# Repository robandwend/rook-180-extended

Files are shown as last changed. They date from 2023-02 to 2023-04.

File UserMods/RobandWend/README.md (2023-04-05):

# ROOK-180 - mods by robandwend (Robertg)

## THIS IS A WORK IN PROGRESS - CHANGES ARE LIKELY

## PLAN

My plan is to build a Rook-180, extended in the Y by 100mm to allow room for 3 hotends (either 3 TD6S's or 4 if I use the Bambu hotends and bowden again) that are give me multi-filament printing.

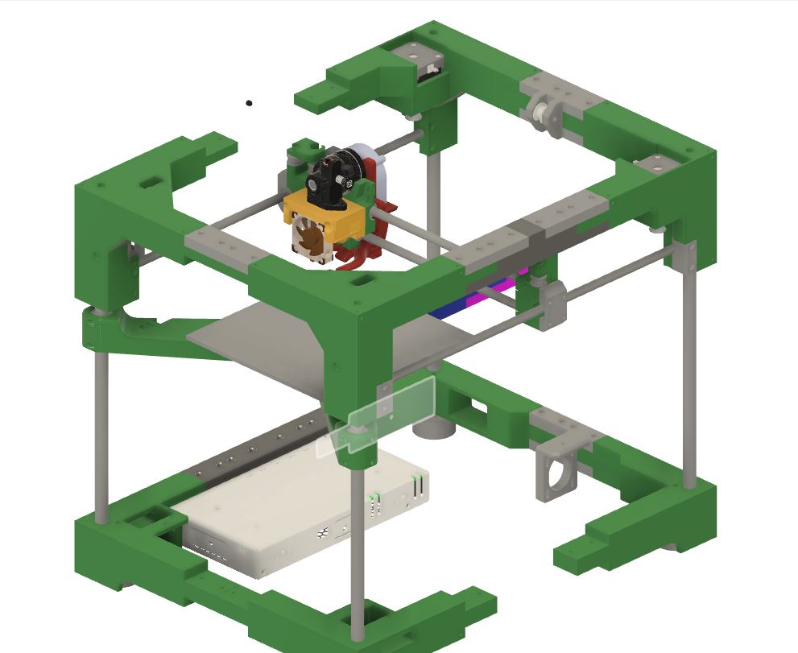
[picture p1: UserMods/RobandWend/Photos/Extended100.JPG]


The bed will still be 180x180, slightly further back (10mm) due to the hotend being rotated 180°. This rotation lets it be driven to the back, where a pair of clips will clip on, and allow the hotend to detatched. The clips on the rear being opened/closed by a strong servo. The hotends will rest on two spikes that fit into the holes on the hotend. (Hopefully this explanation it will make sense as I post more photos). 

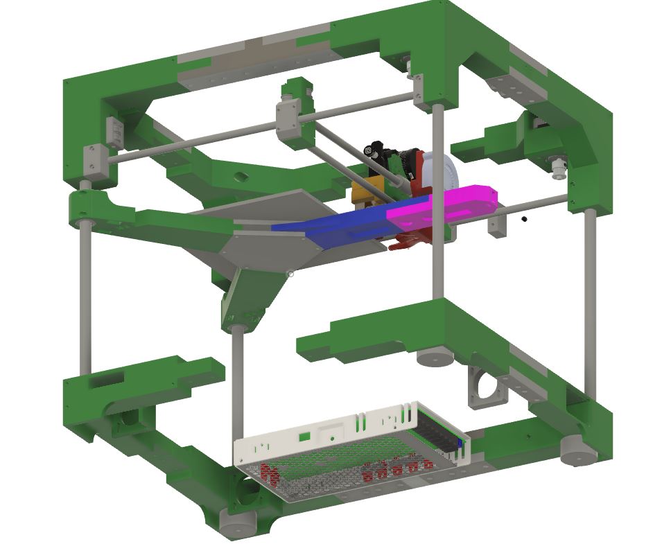
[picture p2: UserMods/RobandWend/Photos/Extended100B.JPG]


Each hotend will need it's own wiring, and will carry the power for the cooling fan. The cooling fan and probe will remain on the X-Carriage, power/cables being passed to it from the removable front.

The hotend design is almost finished - see images. This required squeezing in the magnets, and some position-locking pyramids, I've weight tested the design using simple blocks with the magnets/pyramids and weights etc, and the connection appears very stable and strong. 

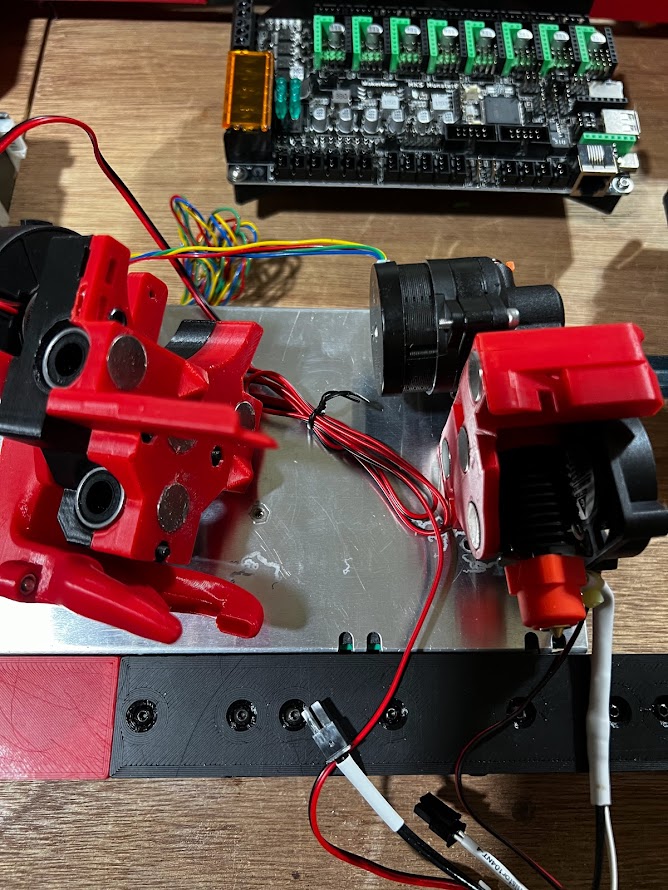
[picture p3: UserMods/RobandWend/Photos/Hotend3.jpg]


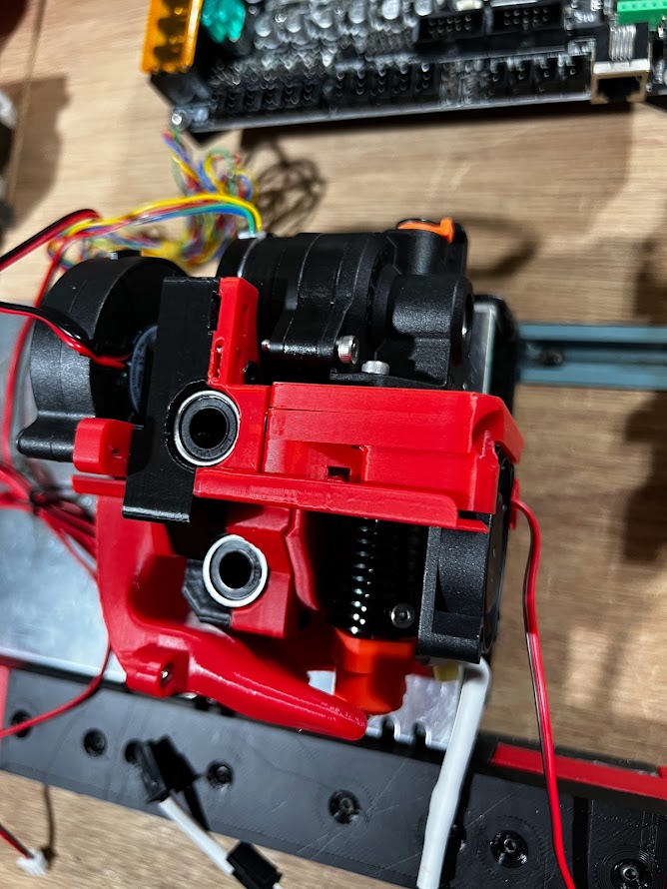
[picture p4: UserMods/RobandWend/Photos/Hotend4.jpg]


The design required me to add 4mm to the front length of the hotend and reducing the rear by 4 - thus keeping the part cooling correctly positioned.

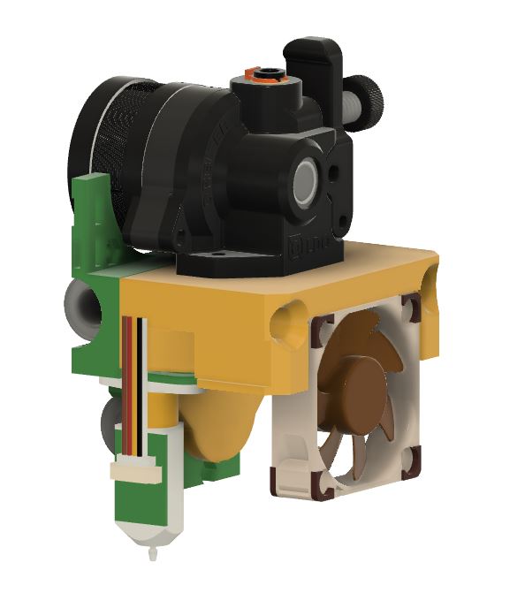
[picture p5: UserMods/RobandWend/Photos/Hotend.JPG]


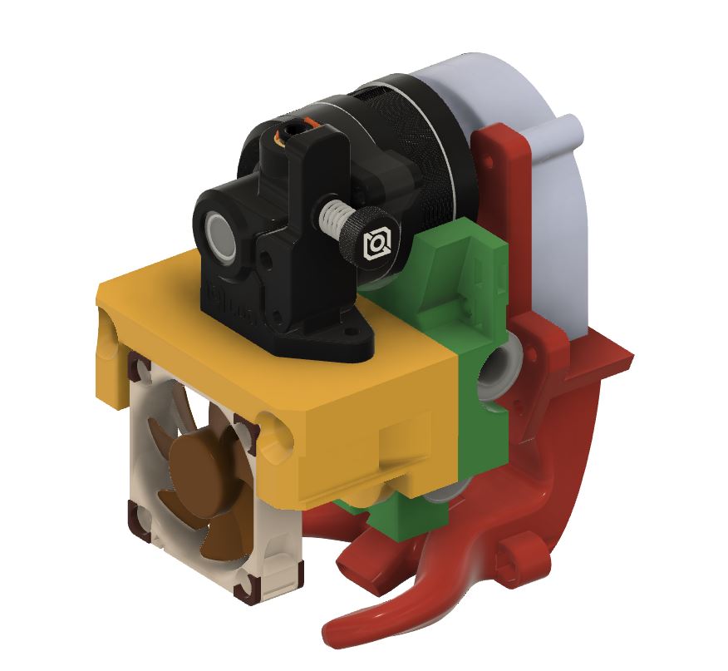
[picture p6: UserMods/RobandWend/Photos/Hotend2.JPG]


I've also had to move the probe back very close to the X rods ** DESIGN NOLONGER HAS THIS CHANGE ** , to allow it to remain with the gantry when the hotends switch. One final thing I need to do is slightly modify the left part cooling pipework to correctly go around the probe.

Here's the current status...

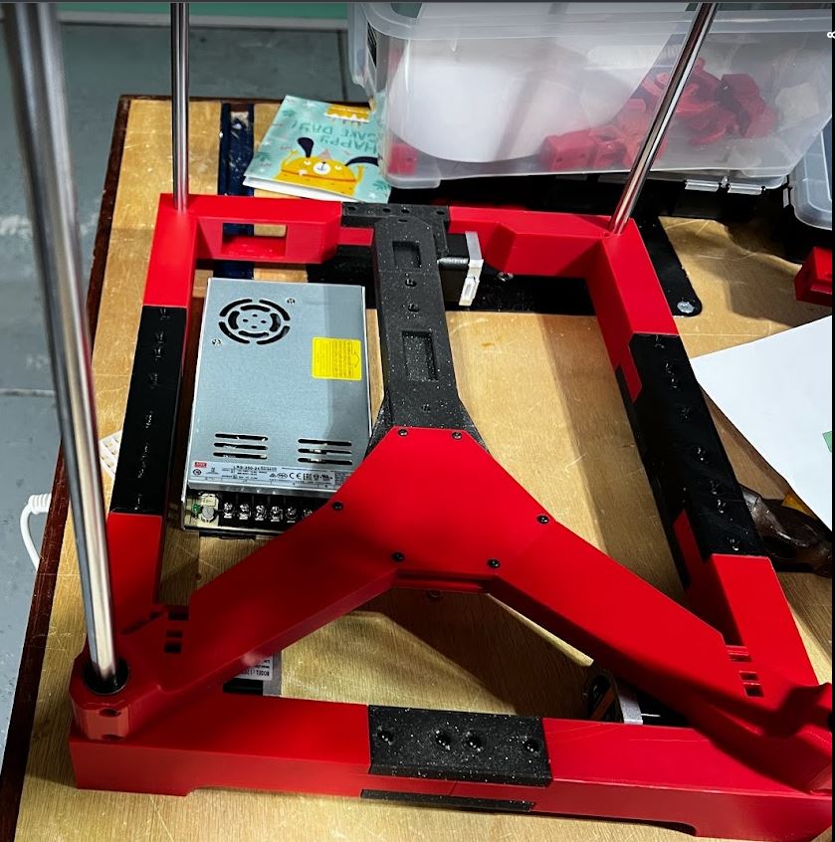
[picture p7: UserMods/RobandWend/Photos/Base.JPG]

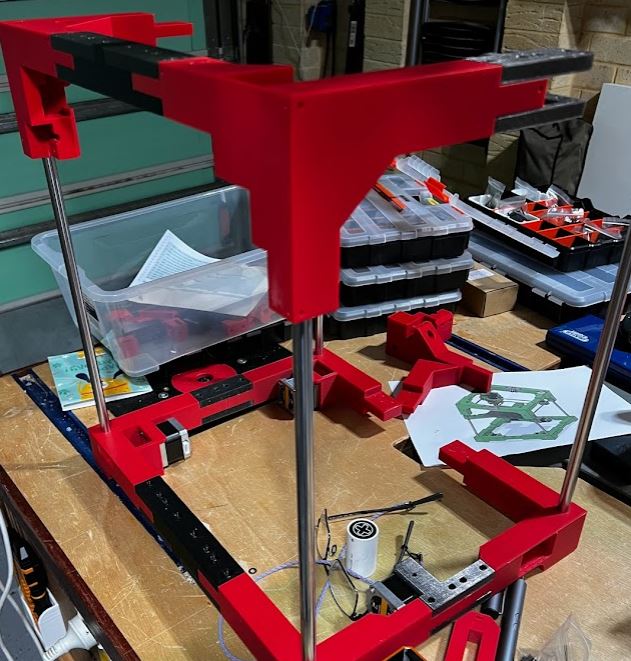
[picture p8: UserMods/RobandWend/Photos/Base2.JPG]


# 12864

Also created a 12864 Display Bracket that fits as a replacement front top brace.

This is not specific to the extended 180

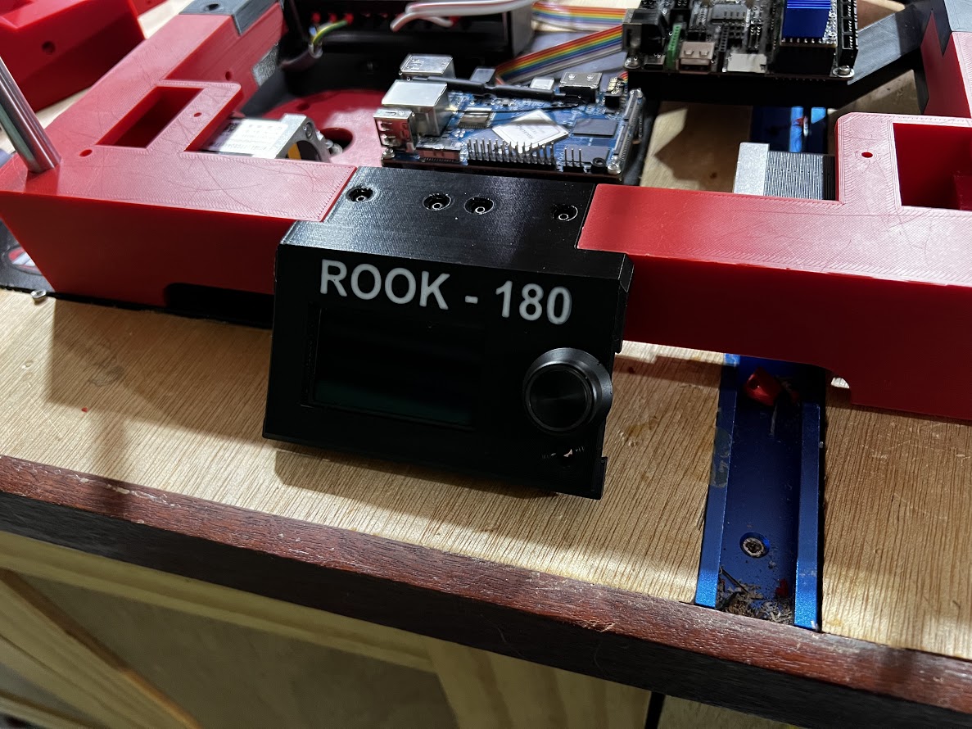
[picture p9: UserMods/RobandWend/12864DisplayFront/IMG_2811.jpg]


# MKS MONSTER8 Mount

This mount is specific to the extended 180, and replaces both the middle lower right braces, extending out to mount the Monster8.

A similar mount it available for an Orange PI 4 LTS based off the front middle brace - as seen in photo below.

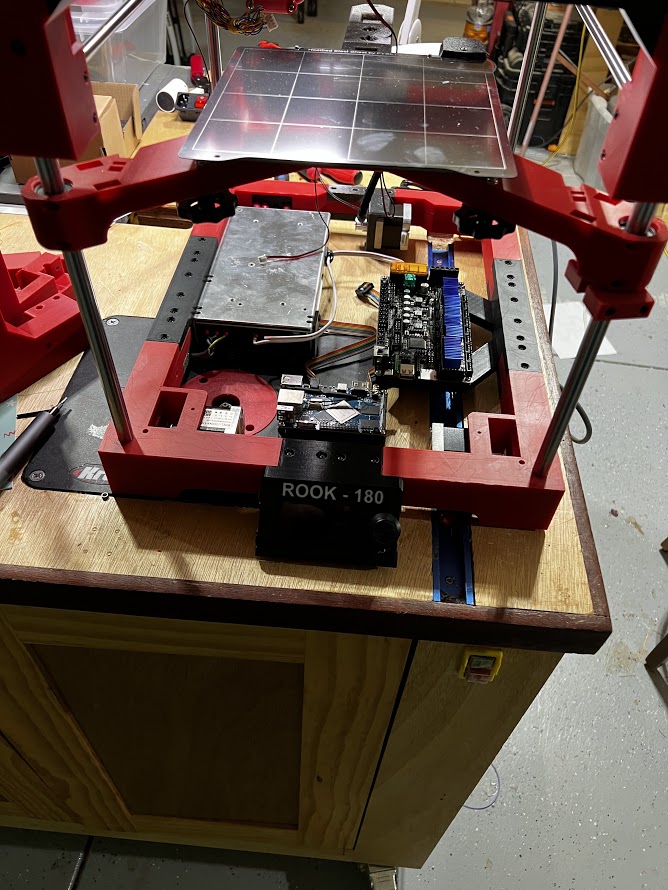
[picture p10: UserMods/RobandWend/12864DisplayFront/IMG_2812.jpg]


# PI MOUNT

There are actually two similar PI mounts available, initially I was using an orangepi 4 LTS, however due to problems getting the gpio working (as a secondary MCU) - I reverted to an raspberry-pi 4b 

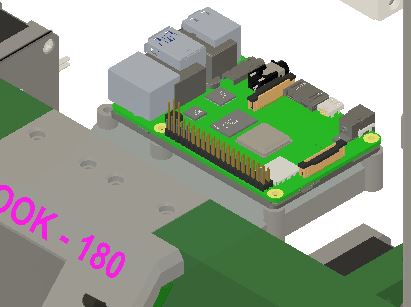
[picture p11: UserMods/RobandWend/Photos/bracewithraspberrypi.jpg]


# MEX - Multi Extruder

## Rear Hotend Storage Area 

To allow for multi-extrude, a rear hotend storage area has been designed.

See videos for design details
* [link](https://www.youtube.com/watch?v=4AOfrqeOWYA) - MEX Development PT1
* [link](https://youtu.be/aWfg_-3LOak) - MEX Development PT2
* [link](https://youtube.com/shorts/aSd3smGOrIA) - MEX Hotend

## Fan cooling and bl-touch

The whole hotend has been reversed (so part cooling fan now at the front). The wiring for the part-cooling fan and the bl-touch remain on the x-carriage at all times. The 5015 adaptor has a small change to allow the wiring to be neatly attached. Current plan is to use a non-functioning piece of bowden to route these two wires to the board. The bl-touch wiring will be routed between the two x-rods.

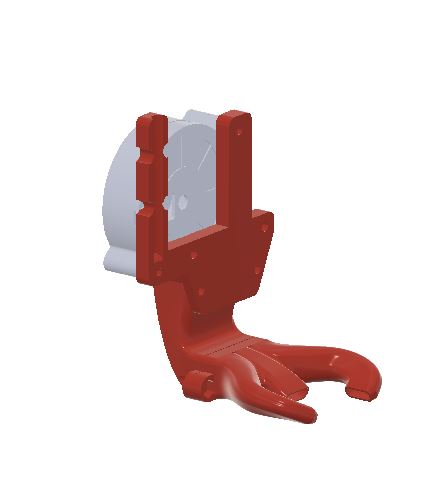
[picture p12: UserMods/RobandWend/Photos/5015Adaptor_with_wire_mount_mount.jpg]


## Bowden Extruders

Clip on bowden extruder mounts (for basic cheapest extruders) have been added

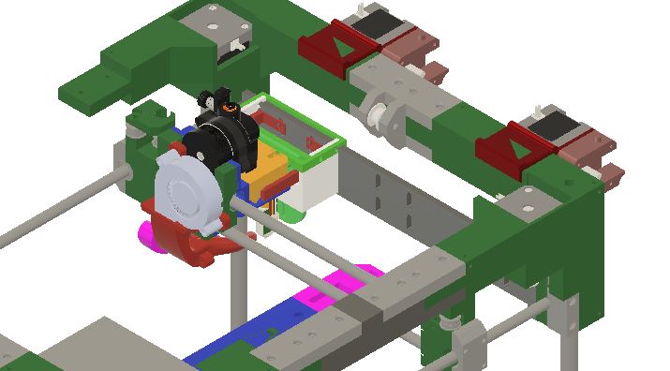
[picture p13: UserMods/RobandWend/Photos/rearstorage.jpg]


Or you could use some Voron M4 Extruders

* [voron design M4 Extruder](https://vorondesign.com/voron_m4)

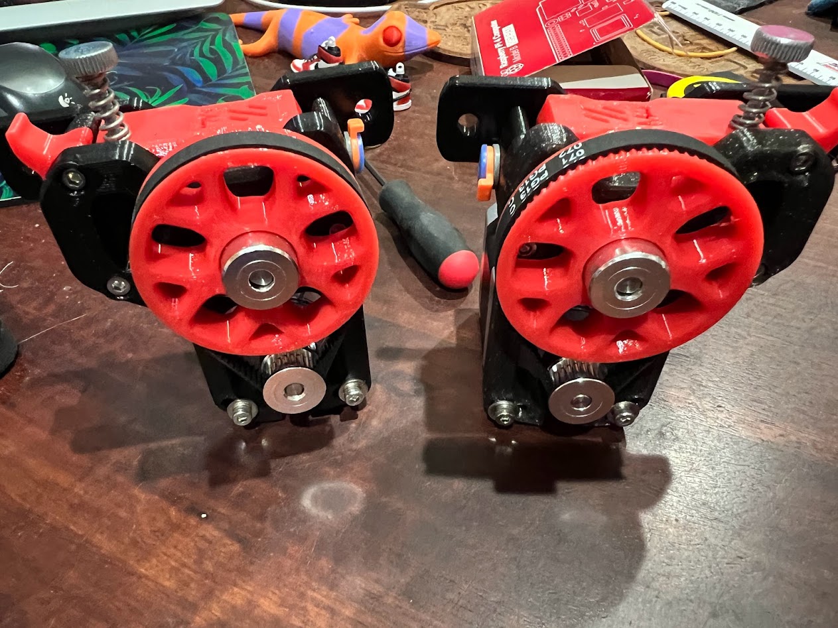
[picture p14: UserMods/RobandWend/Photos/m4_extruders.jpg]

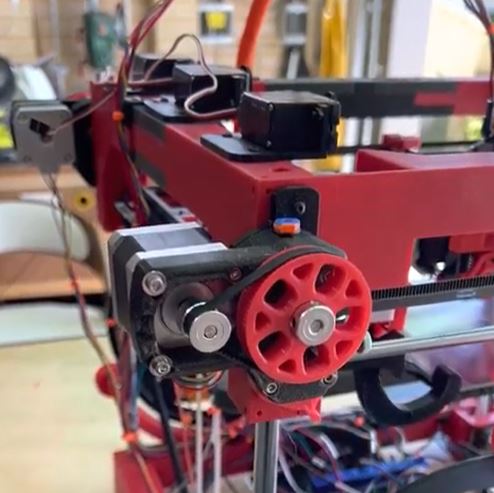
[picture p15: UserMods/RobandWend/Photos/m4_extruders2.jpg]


## Bambu bowden hotend

Since the bambu hotend is quite cheap, and speedwise beats many expensive nozzles, like in my original Rook mods I've added a bambu hotend (for bowden). This has options for either a standard cooling far, or one of the smaller bambu size 2020 fans.

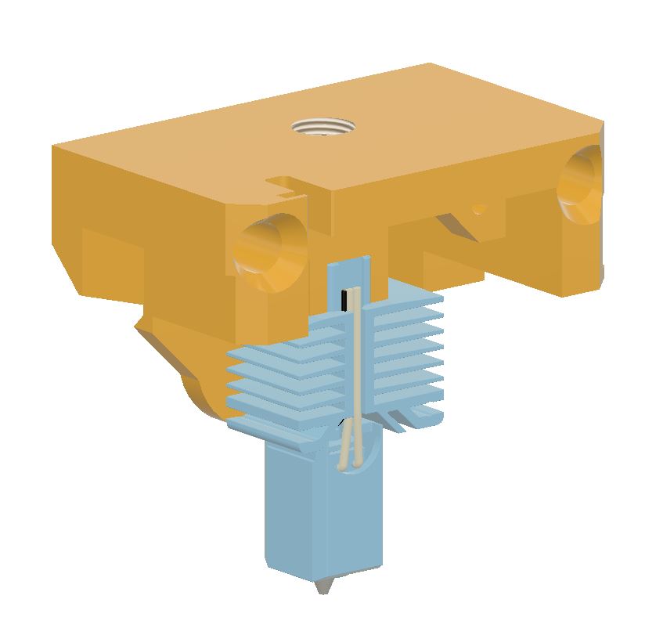
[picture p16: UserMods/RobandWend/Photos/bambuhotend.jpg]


# Endstops
## Z-Endstop

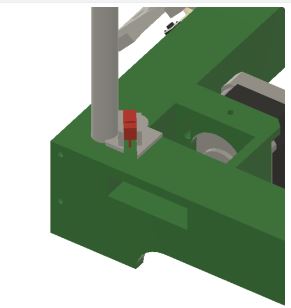
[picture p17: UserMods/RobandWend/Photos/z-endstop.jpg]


# Horseshoe Spool holder

I chose to fit two horseshoe spoolholders to either side

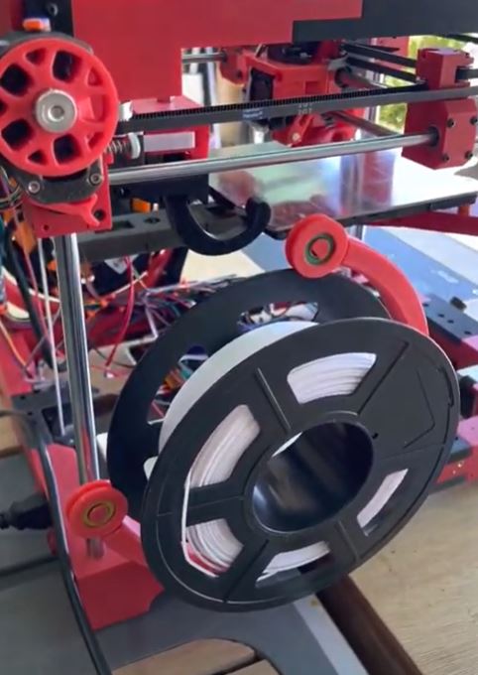
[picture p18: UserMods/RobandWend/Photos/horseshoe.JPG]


From https://github.com/VoronDesign/VoronUsers/tree/master/printer_mods/LoganFraser/HorseshoeSpoolHolder 

Note - for my specific spool size (195mm diameter) a resized STL is provided.

# WIRING - TIDY

I designed a simple wiring scaffold to help keep all the cables tidy.

See [printables link](https://www.printables.com/model/443258-variable-size-scaffold-structure-to-aid-tidying-wi) 

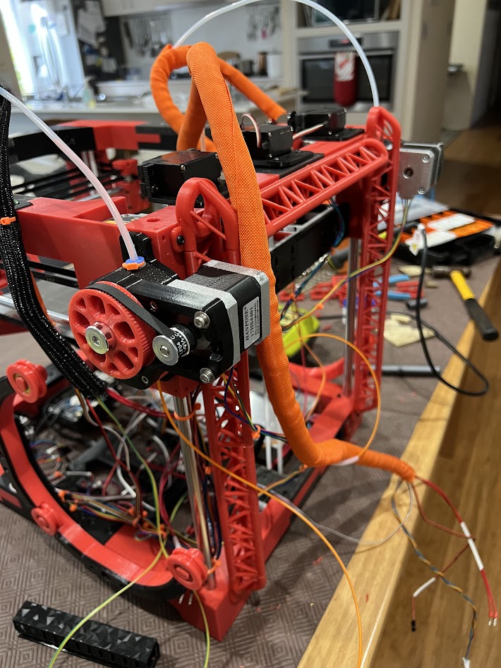
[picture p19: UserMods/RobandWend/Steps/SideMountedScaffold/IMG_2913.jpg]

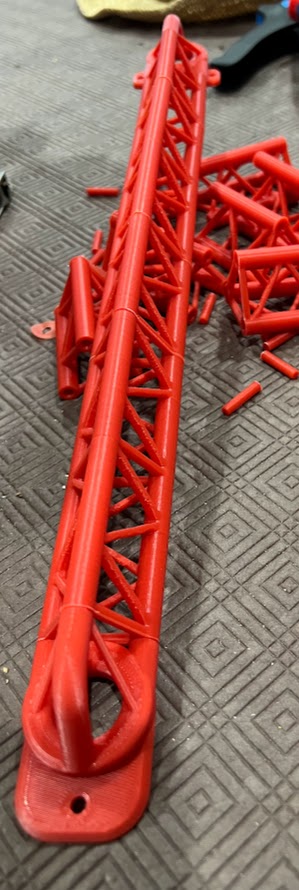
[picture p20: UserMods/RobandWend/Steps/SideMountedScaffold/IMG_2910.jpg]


![Image]()

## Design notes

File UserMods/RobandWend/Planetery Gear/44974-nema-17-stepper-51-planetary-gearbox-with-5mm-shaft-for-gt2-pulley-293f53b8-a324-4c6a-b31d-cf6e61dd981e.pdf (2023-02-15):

## Nema 17 Stepper 5:1 Planetary

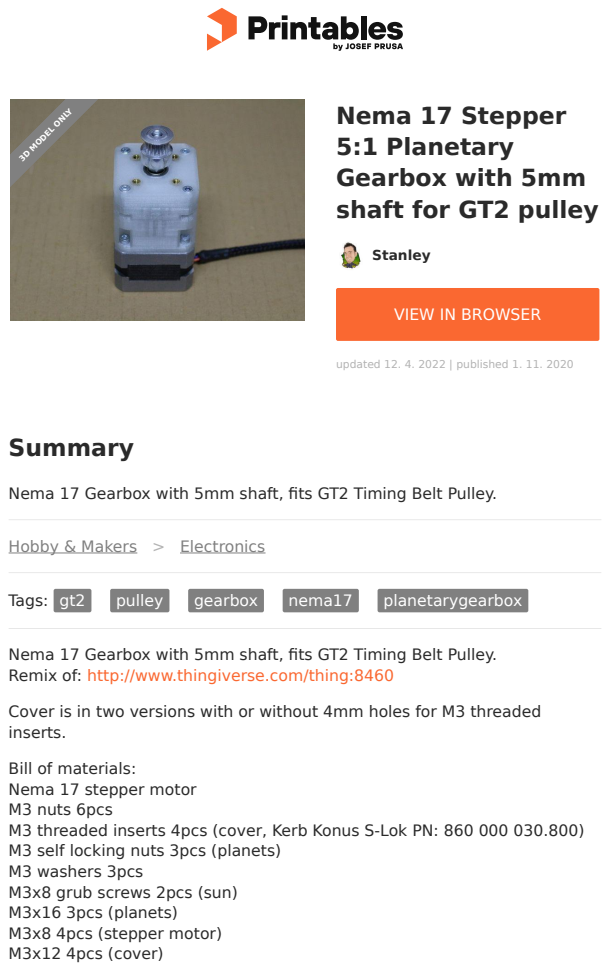
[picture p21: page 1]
Summary; Tags: gt2; pulley; gearbox; nema17; planetarygearbox; Stanley; updated 12. 4. 2022 | published 1. 11. 2020; 3D MODEL ONLY

Gearbox with 5mm
shaft for GT2 pulley

VIEW IN BROWSER (https://www.printables.com/model/44974-nema-17-stepper-51-planetary-gearbox-with-5mm-shaf)

Nema 17 Gearbox with 5mm shaft, fits GT2 Timing Belt Pulley.

Hobby & Makers (https://www.printables.com/model?categoryId=48) > Electronics (https://www.printables.com/model?categoryId=52)

Remix of: http://www.thingiverse.com/thing:8460

Cover is in two versions with or without 4mm holes for M3 threaded
inserts.

Bill of materials:
Nema 17 stepper motor
M3 nuts 6pcs
M3 threaded inserts 4pcs (cover, Kerb Konus S-Lok PN: 860 000 030.800)
M3 self locking nuts 3pcs (planets)
M3 washers 3pcs
M3x8 grub screws 2pcs (sun)
M3x16 3pcs (planets)
M3x8 4pcs (stepper motor)
M3x12 4pcs (cover)

## Model files

M5x30 1pcs (shaft)
M5 self locking nuts 1pcs (shaft)
695zz ball bearing 2pcs (shaft)
683zz ball bearing 6pcs (planets, 2pcs each)

Print instructions

Rafts: No

Supports: Yes

Resolution: 0.1mm - 0.2mm

Infill: 40% - 100%

Notes:

Filament: PET 1.75mm (http://www.filament-pm.cz/) Sliced in: Cura 15.04.2
Nozzle: 0.4mm
Shell thickness: 1.2mm
Bottom/Top thickness: 1.2mm Print speed: 30mm/s
Print temp: 235°C
Bed temp: 80°C
Planets and sun printed in 0.1mm layer height with 100% infill. Other parts in 0.2mm layer height with 40% infill.

cover.stl

cover_inserts.stl

housing.stl

Find source .stl files on Thingiverse.com (https://www.thingiverse.com/thing:1141146)

## License

This work is licensed under a
Creative Commons (International License)

Public Domain (https://creativecommons.org/share-your-work/public-domain/cc0/)

✔ | Sharing without ATTRIBUTION
✔ | Remix Culture allowed
✔ | Commercial Use
✔ | Free Cultural Works
✔ | Meets Open Definition

planet.stl

carrier.stl

sun.stl

nema_17_gearbox.skp

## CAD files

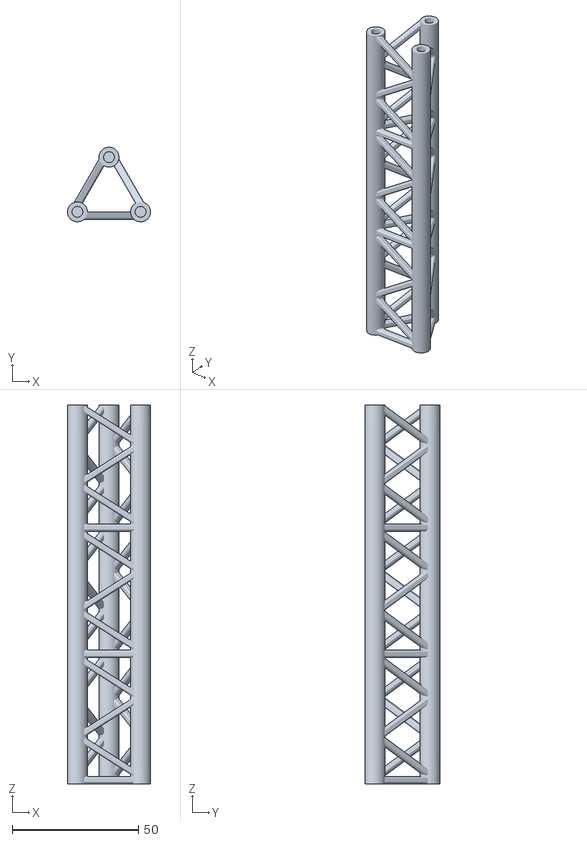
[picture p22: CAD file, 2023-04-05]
UserMods/RobandWend/Steps/SideMountedScaffold/MainBody150.stl
32.9 x 29.5 x 150.0

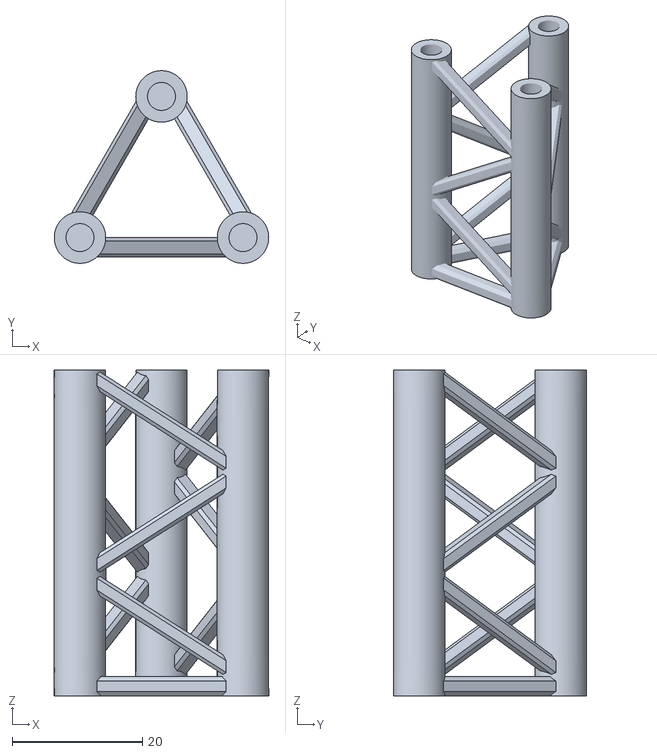
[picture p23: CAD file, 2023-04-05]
UserMods/RobandWend/Steps/SideMountedScaffold/MainBody50mm.stl
32.9 x 29.5 x 50.0

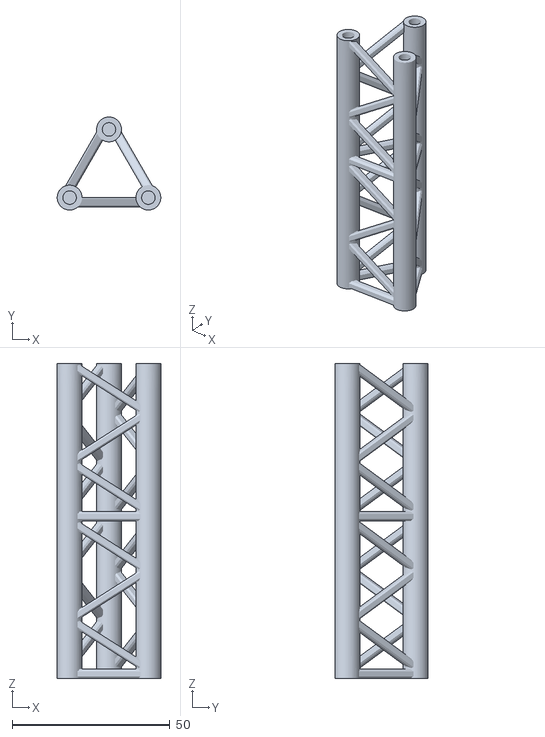
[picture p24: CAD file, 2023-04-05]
UserMods/RobandWend/Steps/SideMountedScaffold/MainBody100.stl
32.9 x 29.6 x 100.0

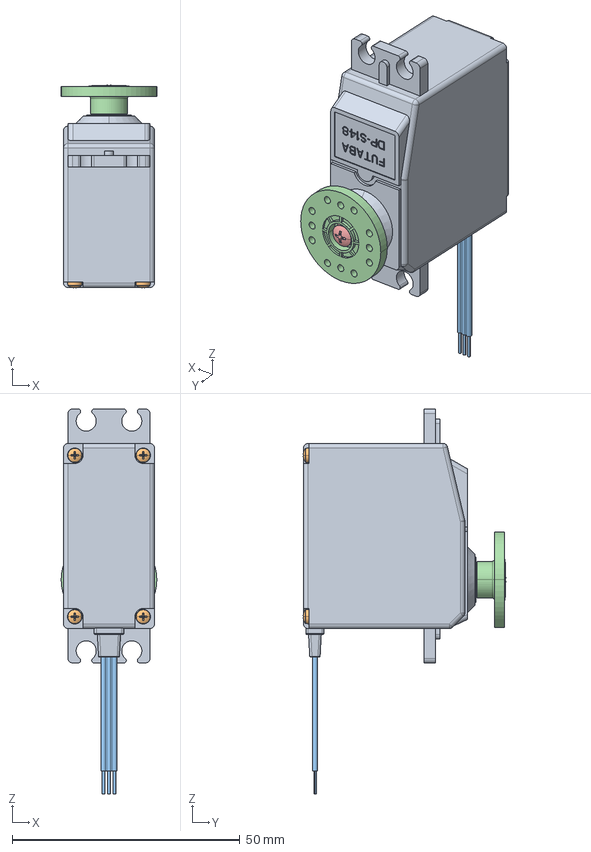
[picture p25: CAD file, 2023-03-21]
UserMods/RobandWend/Steps/servo-futaba-sp-s148_asm.stp
21.0 x 44.4 x 84.5 mm
SERVO-FUTABA-FP-S148-BOX
VIS-M16X3-DIN7985-PHILIPS x 4
WIRE-20AWG-RIBBON-3-30
SERVO-HORN-C-DISK-FSH6R
VIS-M25X8-DIN7985-PHILIPS

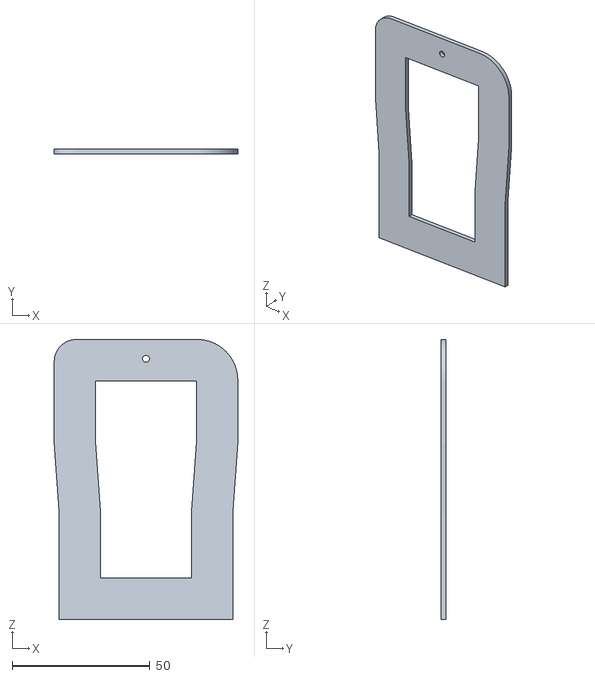
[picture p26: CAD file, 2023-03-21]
UserMods/RobandWend/Steps/FullPushDownBar.stl
66.6 x 1.80 x 101.5

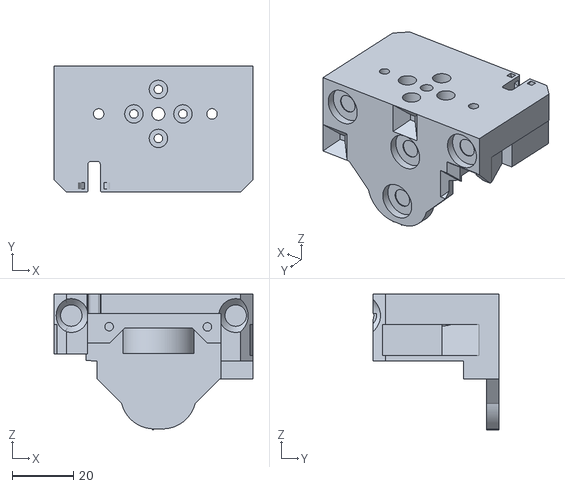
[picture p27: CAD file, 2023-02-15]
UserMods/RobandWend/Steps/ToolheadMainBody.stl
65.0 x 41.1 x 44.3

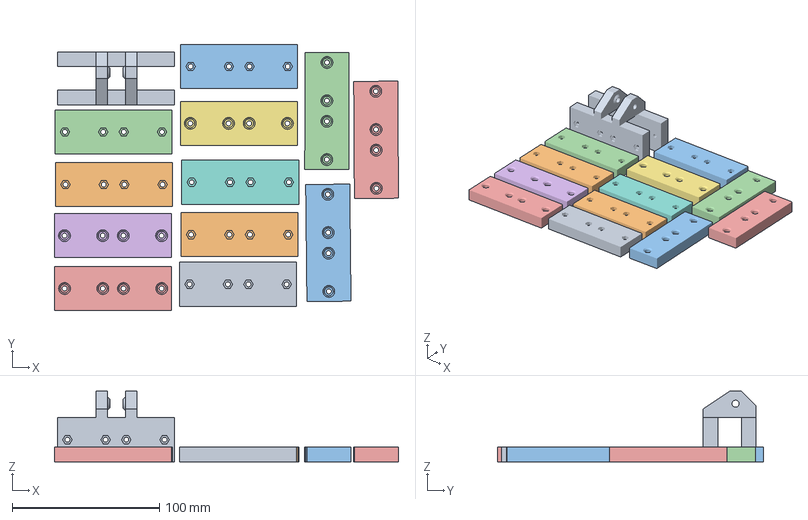
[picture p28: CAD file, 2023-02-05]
UserMods/RobandWend/BambuPlates/PrusaPlate-Black.3mf
233.9 x 180.9 x 48.0 mm
1 x Rear_Upper_Brace.stl
3 x Frame_Lower_Brace.stl x 2
3 x Frame_Upper_Brace.stl x 2

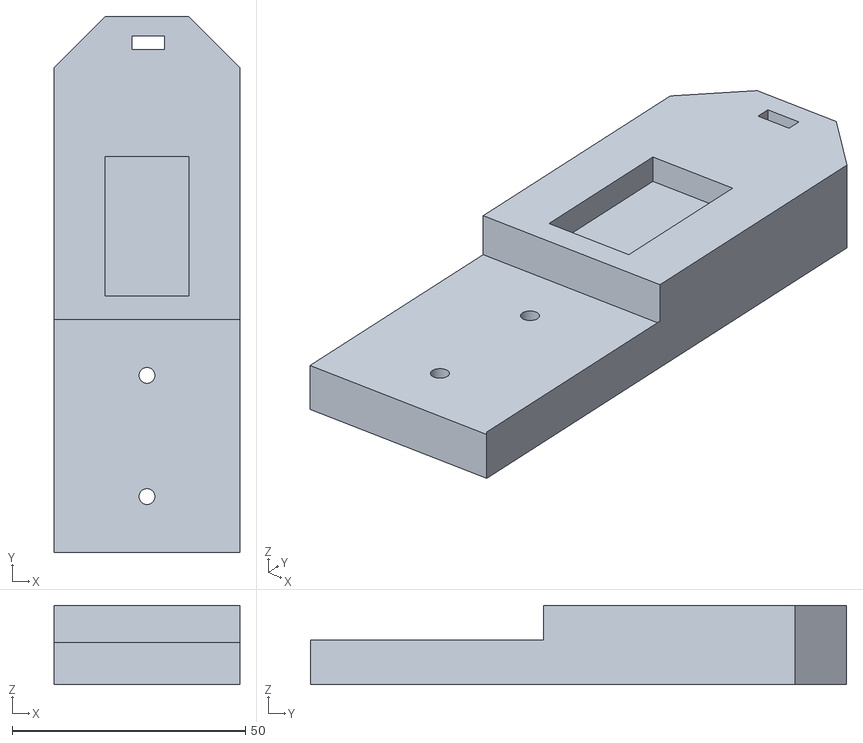
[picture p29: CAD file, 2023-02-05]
UserMods/RobandWend/Multi_Hotend/STL/ReplacementArmPart2.stl
39.9 x 115.0 x 17.0

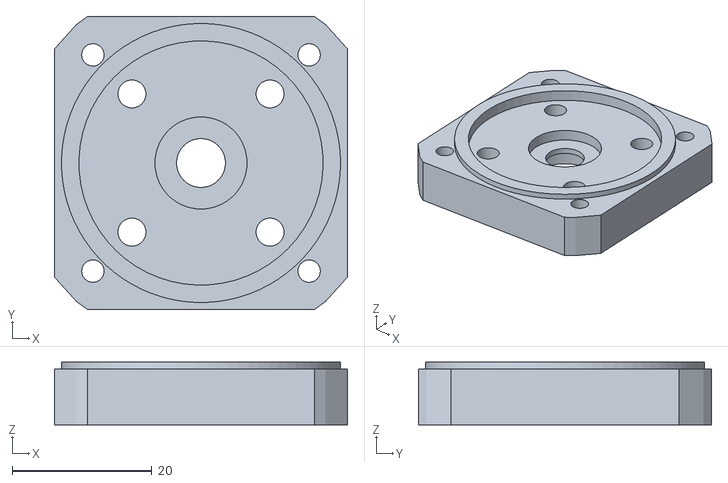
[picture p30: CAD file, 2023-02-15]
UserMods/RobandWend/Planetery Gear/cover_inserts.stl
42.0 x 42.0 x 9.00

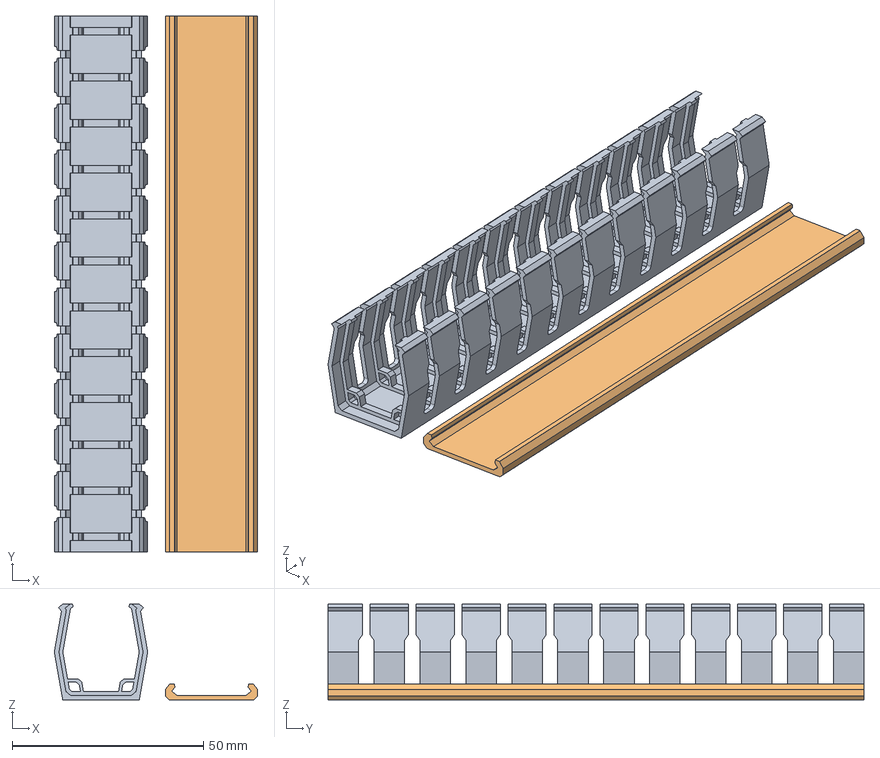
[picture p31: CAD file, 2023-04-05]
UserMods/RobandWend/Steps/CableManagementDuct v1.step
53.1 x 140.0 x 25.0 mm

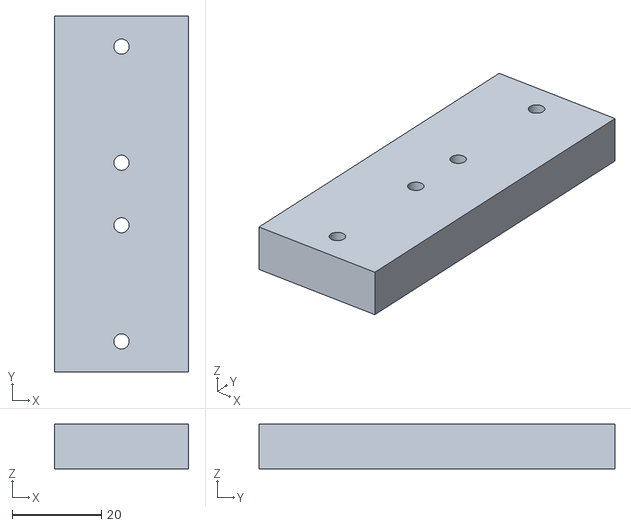
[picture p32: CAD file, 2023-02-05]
UserMods/RobandWend/Multi_Hotend/STL/2xBottomBrace1.stl
30.0 x 79.6 x 10.0

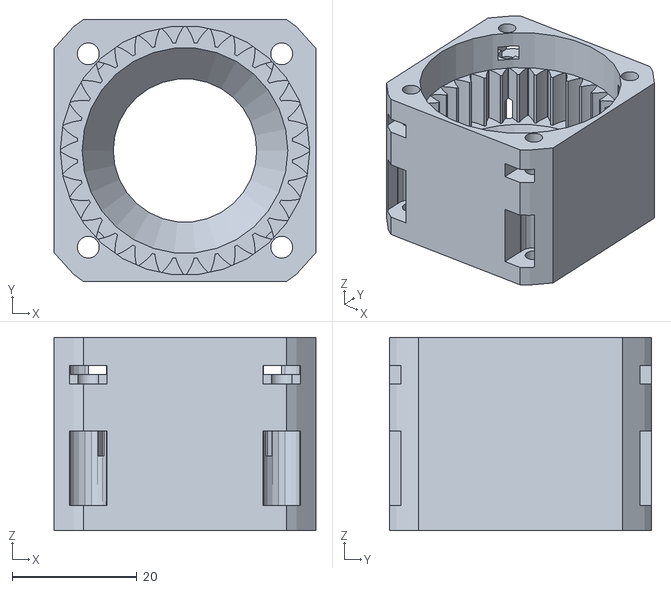
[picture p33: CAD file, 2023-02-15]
UserMods/RobandWend/Planetery Gear/housing.stl
42.0 x 42.0 x 31.0

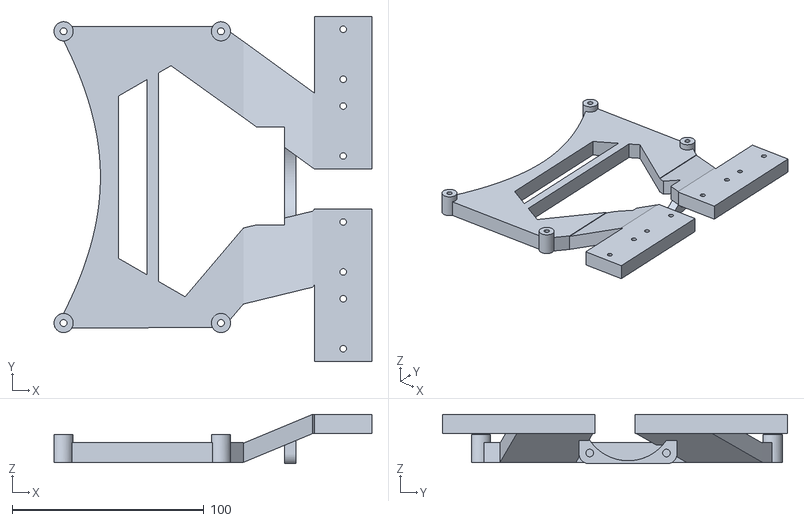
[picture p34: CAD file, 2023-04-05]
UserMods/RobandWend/Steps/Brace with Monster.stl
165.7 x 180.0 x 25.6

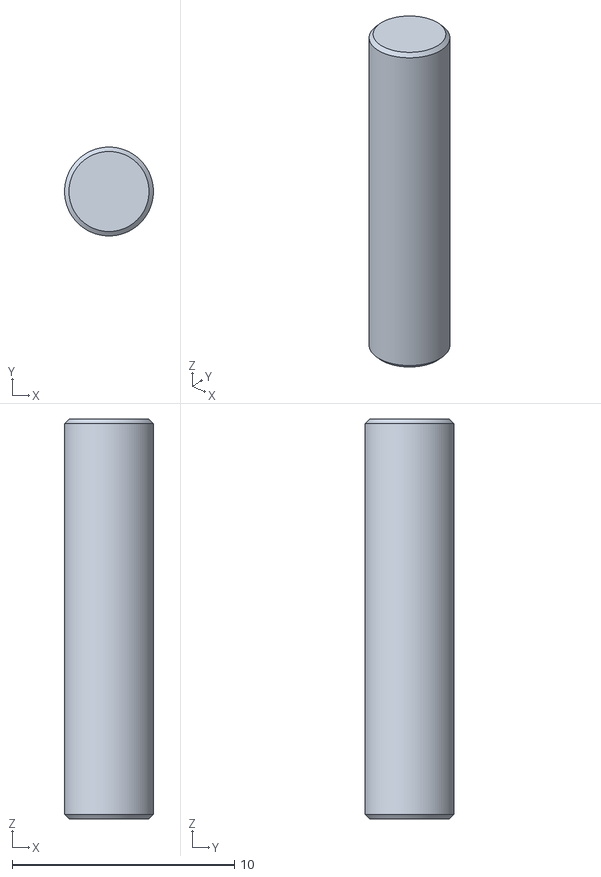
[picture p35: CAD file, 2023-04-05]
UserMods/RobandWend/Steps/SideMountedScaffold/Peg.stl
4.00 x 4.00 x 18.0

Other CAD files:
UserMods/RobandWend/Multi_Hotend/STL/ReplacementArmPart1.stl
UserMods/RobandWend/Planetery Gear/cover.stl
UserMods/RobandWend/Steps/OrbiterWireMount.stl
UserMods/RobandWend/Multi_Hotend/STL/2xTopBrace1.stl
UserMods/RobandWend/12864DisplayFront/12864ForRook.stl
UserMods/RobandWend/12864DisplayFront/12864_Color_4Bambu.3mf
UserMods/RobandWend/Multi_Hotend/STL/2xBottomExtension.stl
UserMods/RobandWend/Multi_Hotend/STL/2xTopExtension.stl
UserMods/RobandWend/Planetery Gear/carrier.stl
UserMods/RobandWend/Planetery Gear/nema_17_gearbox.skp
UserMods/RobandWend/Planetery Gear/planet.stl
UserMods/RobandWend/Planetery Gear/sun.stl
UserMods/RobandWend/Steps/5015_Adapter.stl
UserMods/RobandWend/Steps/5050 TO 4040 Fan Converter.stl
UserMods/RobandWend/Steps/BLTouchStrengthener.stl
UserMods/RobandWend/Steps/BarSpreader.stl
UserMods/RobandWend/Steps/BodyTopFrontLeft-2mmExtraRod.stl
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

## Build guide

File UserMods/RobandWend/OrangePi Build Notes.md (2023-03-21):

# ORANGE PI 4 LTS KLIPPER BUILD NOTES

## NOTE: Initially tried installing using debian - Klipper worked fine, but setting up the4 pi to be a secondary MCU failed as I counldnt get the gpio visible.

1. Downloaded UBUNTO (Server) Orangepi4-lts_3.0.6_ubuntu_jammy_server_linux5.18.5.img from Orange PI download page (https://drive.google.com/drive/folders/1t6n1XnacRC2HCqAAzv6CXl5UxZ0F2Gsx) 

2. Used raspberry-pi-imager to image the iso onto sd-card

- sudo apt update

3. Change hostname

- sudo vi /etc/hostname
- sudo vi /etc/hosts

4. Enable wireless

Follow instructions here https://www.linuxbabe.com/ubuntu/connect-to-wi-fi-from-terminal-on-ubuntu-18-04-19-04-with-wpa-supplicant

5. Install klipper using https://github.com/th33xitus/kiauh
 
 - sudo su
 - apt-get update
 - apt-get install git -y
 - exit (from root)
 - cd ~ && git clone https://github.com/th33xitus/kiauh.git
 
6. Run kiauh
 
 - ./kiauh/kiauh.sh
 
 Install klipper (python3) / 
 Install moonraker
 
7. Install pi secondary mcu 

as per https://www.klipper3d.org/RPi_microcontroller.html
 
**gpio pinout on orangepi - https://uthings.uniud.it/control-gpio-pins-of-orange-pi-boards**

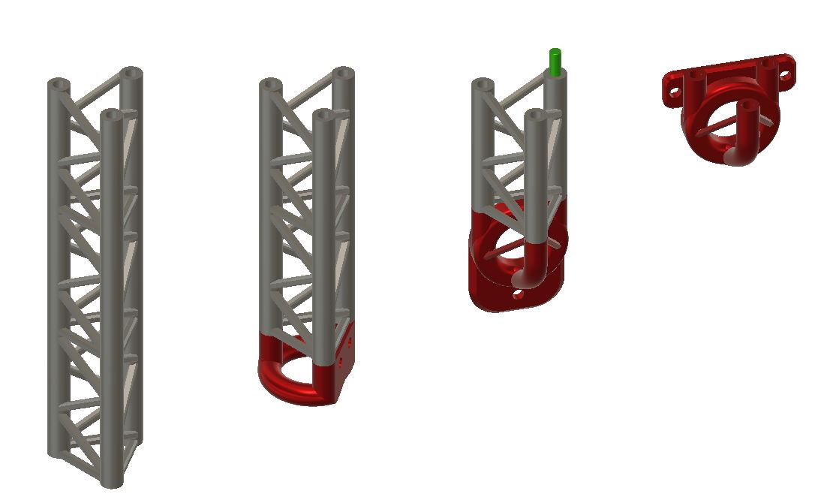
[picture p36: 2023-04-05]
UserMods/RobandWend/Steps/SideMountedScaffold/img.JPG

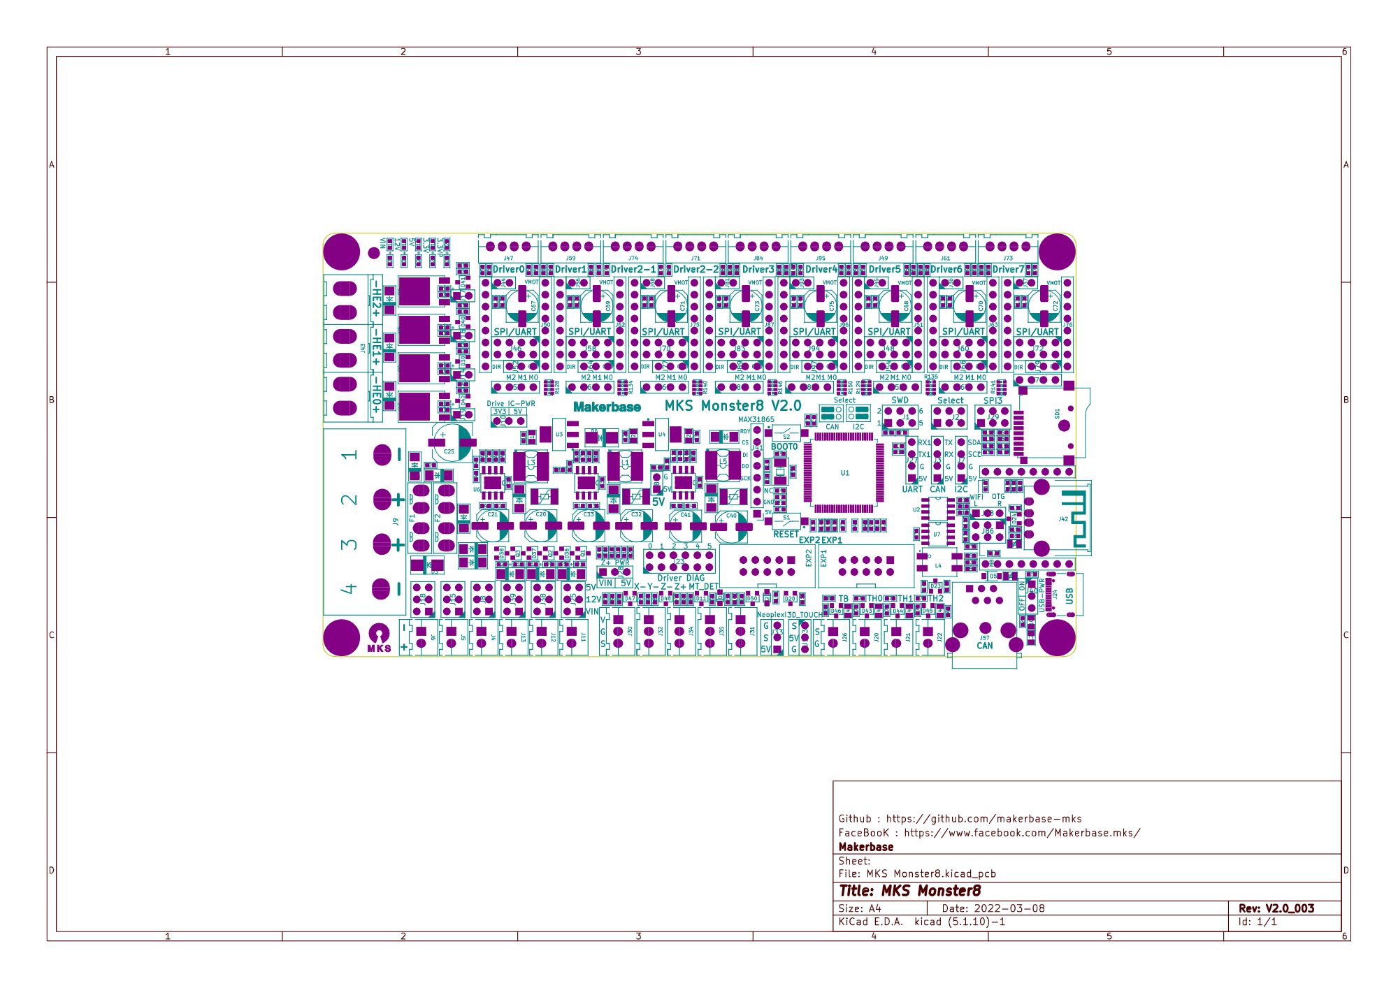
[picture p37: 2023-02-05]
UserMods/RobandWend/Steps/download.png

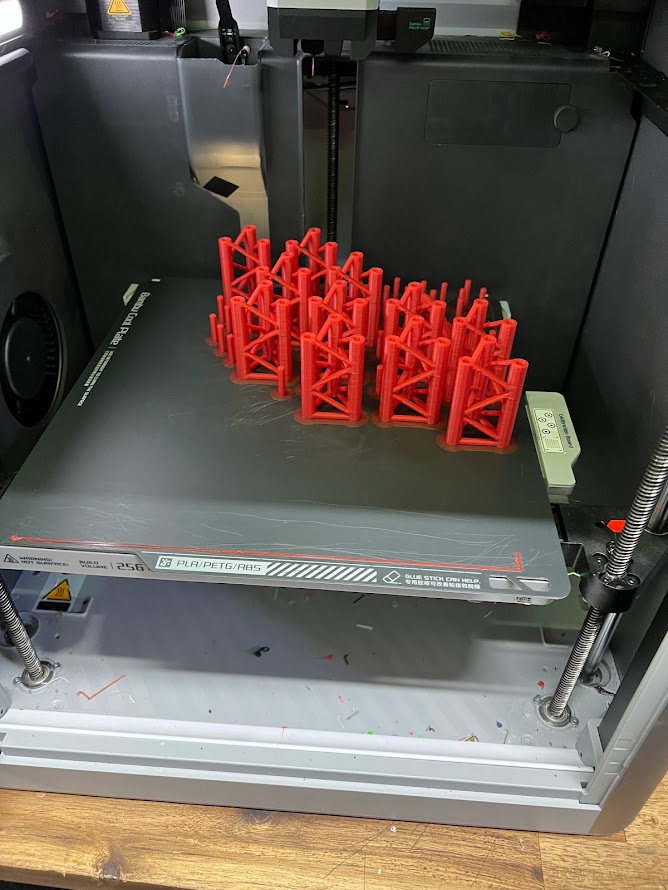
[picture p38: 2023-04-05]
UserMods/RobandWend/Steps/SideMountedScaffold/IMG_2908.jpg

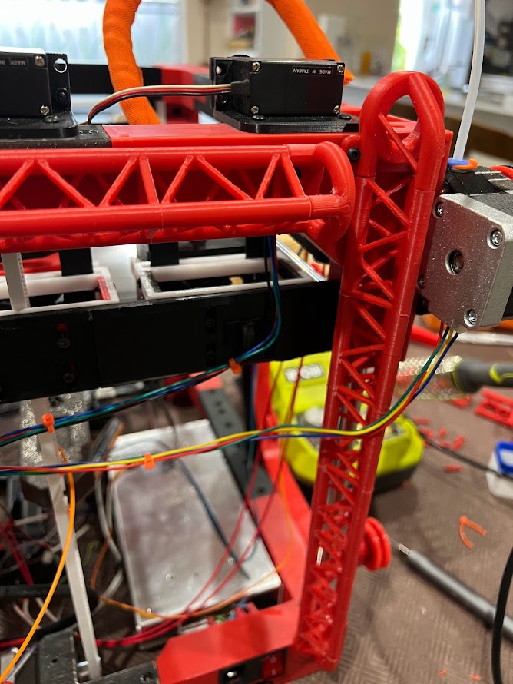
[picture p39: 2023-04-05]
UserMods/RobandWend/Steps/SideMountedScaffold/IMG_2911.jpg

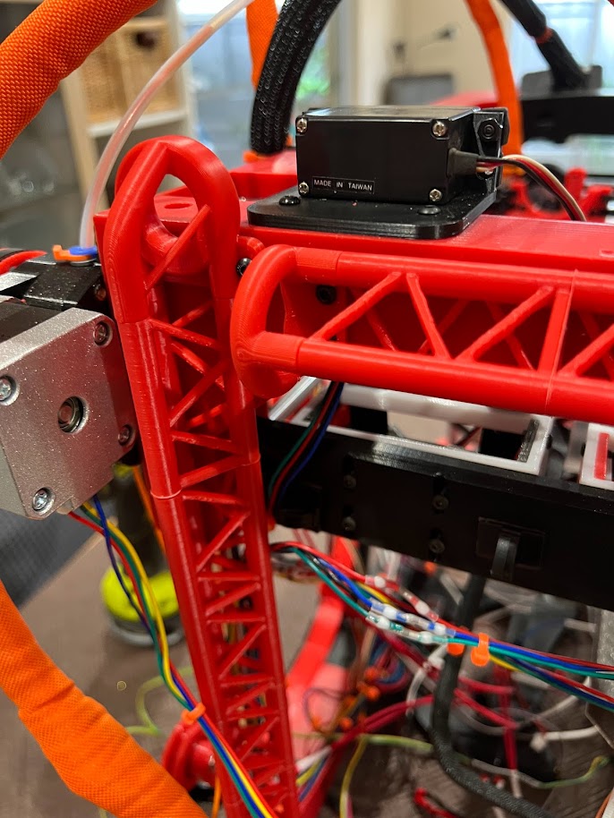
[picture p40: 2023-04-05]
UserMods/RobandWend/Steps/SideMountedScaffold/IMG_2912.jpg

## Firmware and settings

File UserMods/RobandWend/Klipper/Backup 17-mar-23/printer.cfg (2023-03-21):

[include fluidd.cfg]
[include steppers.cfg]
[include display.cfg]
[include loadunload.cfg]
[include bltouch.cfg]

[mcu]
# serial: /dev/serial/by-id/usb-Klipper_stm32f407xx_310031000D50304B57383620-if00
serial: /dev/serial/by-id/usb-Klipper_stm32f407xx_2B0052000E50304B57383620-if00
restart_method: command

[mcu host]
serial: /tmp/klipper_host_mcu

[heater_bed]
heater_pin: PB10
sensor_type: EPCOS 100K B57560G104F
sensor_pin: PC0
#control: watermark
min_temp: 0
max_temp: 130


#Printer Speeds and Accels
[printer]
kinematics: corexy
max_velocity: 300
max_accel: 10000 # change this to 7500 after commissioning
max_z_velocity: 15   # may be able to increase to 15 after comissioning.
max_z_accel: 50
square_corner_velocity: 4 # start at 8, but then increase once you're sure assembly is sound


#*# <---------------------- SAVE_CONFIG ---------------------->
#*# DO NOT EDIT THIS BLOCK OR BELOW. The contents are auto-generated.
#*#
#*# [heater_bed]
#*# control = pid
#*# pid_kp = 56.418
#*# pid_ki = 0.594
#*# pid_kd = 1339.224

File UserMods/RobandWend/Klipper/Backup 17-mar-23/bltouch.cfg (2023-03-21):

[bltouch]
sensor_pin: ^PB12
control_pin: PA8
x_offset: -20
y_offset:  5
z_offset: 1.2
probe_with_touch_mode: false
stow_on_each_sample: true
pin_up_reports_not_triggered: false

[z_tilt]
horizontal_move_z: 12
# Order of steppers = back, f-left, f-right
z_positions:
    76,194
    5,5
    148,5
#    110, 220
#    40, 30
#    180, 30
points:
    76,144
    5,5
    148,5
speed: 150
retries: 7
retry_tolerance: 0.015

#[safe_z_home]
#home_xy_position: 90, 90 # Change coordinates to the center of your print bed
#speed: 50
#z_hop: 0                 # Move up 10mm
#z_hop_speed: 5

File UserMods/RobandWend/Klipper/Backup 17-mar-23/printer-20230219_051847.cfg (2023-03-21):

[include fluidd.cfg]
# [include display.cfg]

[mcu]
serial: /dev/serial/by-id/usb-Klipper_stm32f407xx_310031000D50304B57383620-if00
restart_method: command

[heater_bed]
heater_pin: PB10
sensor_type: EPCOS 100K B57560G104F
sensor_pin: PC0
control: watermark
min_temp: 0
max_temp: 130

# Stepper Configs
[stepper_x]
step_pin: PC14
dir_pin: PC13
enable_pin: !PC15
microsteps: 16
rotation_distance: 40
# endstop_pin: tmc2209_stepper_x:virtual_endstop 
endstop_pin: !PA14  # PA13 for X-max; endstop have'!' is NO
position_endstop: 0
position_max: 180
homing_speed: 100

# [tmc2209 stepper_x] 
# uart_pin: PE6
# run_current: .9
# sense_resistor: 0.110
# stealthchop_threshold: 0
# interpolate: False
# diag_pin: PA14
# driver_SGTHRS: 130


[stepper_y]
step_pin: PE5
dir_pin: !PE4
enable_pin: !PC15
microsteps: 16
rotation_distance: 40
# endstop_pin: tmc2209_stepper_y:virtual_endstop 
endstop_pin: !PA15  # PA13 for X-max; endstop have'!' is NO
position_endstop: 0
position_max: 180
homing_speed: 100


# [tmc2209 stepper_y] 
# uart_pin: PE3
# run_current: .9
# sense_resistor: 0.110
# stealthchop_threshold: 0
# interpolate: False
# diag_pin: PA15
# driver_SGTHRS: 130



[stepper_z]
step_pin: PE1
dir_pin: PE0
enable_pin: !PE2
microsteps: 16
rotation_distance: 8
endstop_pin: !PB13  # PB12 for Z-max; endstop have'!' is NO
position_endstop: 0
position_max: 180
homing_speed: 25

[stepper_z1]
step_pin: PB5
dir_pin: PB4
enable_pin: !PB6
microsteps: 16
rotation_distance: 8
endstop_pin: !PB13  # PB12 for Z-max; endstop have'!' is NO

[stepper_z2]
step_pin: PD6
dir_pin: PD5
enable_pin: !PD7
microsteps: 16
rotation_distance: 8
endstop_pin: !PB13  # PB12 for Z-max; endstop have'!' is NO

[printer]
kinematics: cartesian
max_velocity: 10000
max_accel: 20000
max_z_velocity: 100
max_z_accel: 1000

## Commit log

2023-02-05 WIP / Added screen mount
    [12864ForRook.stl, 12864_Color_4Bambu.3mf, 2xBottomBrace1.stl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]
2023-02-15 Mounts added
    [BarSpreader.stl, ExtruderMount.stl, Foot.stl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]
2023-04-05 Added scaffold
    [Brace with Monster.stl, CableManagementDuct v1.step, MainBody100.stl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]
